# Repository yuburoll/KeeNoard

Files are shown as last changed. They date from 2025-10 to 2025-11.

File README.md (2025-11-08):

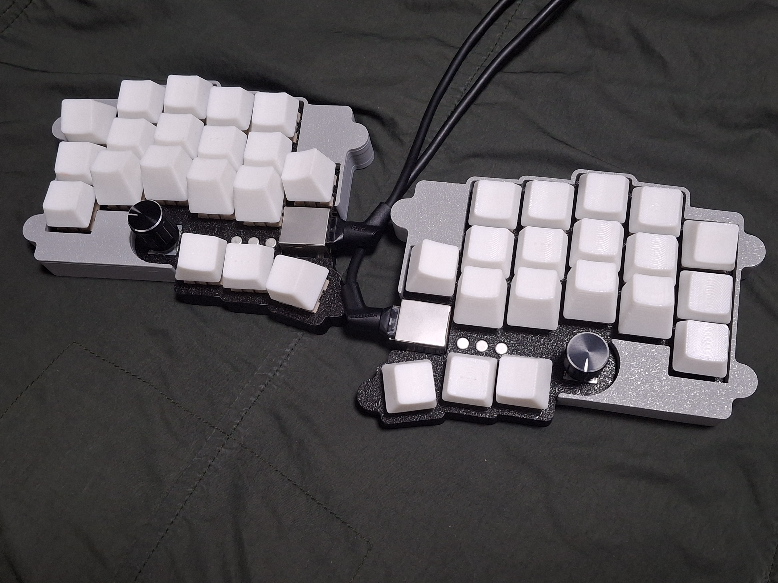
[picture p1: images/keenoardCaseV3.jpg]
keenoardCaseV3


# KeeNoard

**KeeNoard**(name intended typo between B and N) is 38-key split keyboard with rotary encoder and multiple center key, with only one rp2040 zero board.

Inspired and learned many thing from the former great [Cheapino](https://github.com/tompi/cheapino), KeeNoard uses only one board and [Japanese duplex matrix](https://kbd.news/The-Japanese-duplex-matrix-1391.html), and controlled ghosting with three PNP transistor and active-high matrix.

Default keymap uses customized [Miryoku](https://github.com/manna-harbour/miryoku) - with slight different mouse and navigator keys. Two center keys are mapped to left Y and right B, which are originally intended.

## Preparation

- 1x rp2040 zero (boards formly created by waveshare) (Approx. 2-4$)

- 2x KeeNoard PCB Boards (5 boards are 9$ on JLC w/o shipping cost)

- 1x printed case sets, which you want to make it (Approx. 8-12$ if you buy printed one)

- 6x TO-18 PNP transistors, or 6x SOT-23 PNP transistors. (Approx. 1-2$)

- 50x diodes (Approx. 1$)

- 2x EC11 encoders and cap (Approx. 2$)

- 14x M2x6 screws, flathead (Approx. 1$)

- 1x RJ45 cable (Approx. 3$)

- 2x RJ45 connector, in 18mm (Approx. 1$)

- 38x Keyswitches & Keycaps (Maybe this costs varies too much. 15$ on average)

Approx. 43$-50$(w/o shipping cost) needed to build one

## Build Guides

work in progress. sorry!

You can see the images in the folder, which uploaded for build guides. Especially you may see how to solder the controller board, because this uses surface mounting by castelated pins.

Images are captured with prototype version PCB, which is different from the current gerber. current gerber has SMD transistor soldering pads on the protype's label position, and is more easy to solder controller board with larger soldering pads.

This uses [qmk](https://qmk.fm/) to build the firmware. Copy "keenoard" folder which is in "firmware" directory to "qmk_firmware\keyboards" folder, and build it via qmk msys.

Or, simply flash uf2 in "uf2Examples" folder by changing rp2040 zero in dfu mode, which can be executed by holding boot button while plugging in usb c. Vial versions are also prepared - use proper vial firmware, depending on where you placed the controller board.

## Licenses

matrix.c and other qmk-related things follows GNU GPL license.

other codes follows MIT license.

all designs and the hardware board follows CC BY-SA 4.0 license.

If you want to make a commercial product, it would be appreciated [if you sponsor some bucks for me.](https://github.com/sponsors/yuburoll)

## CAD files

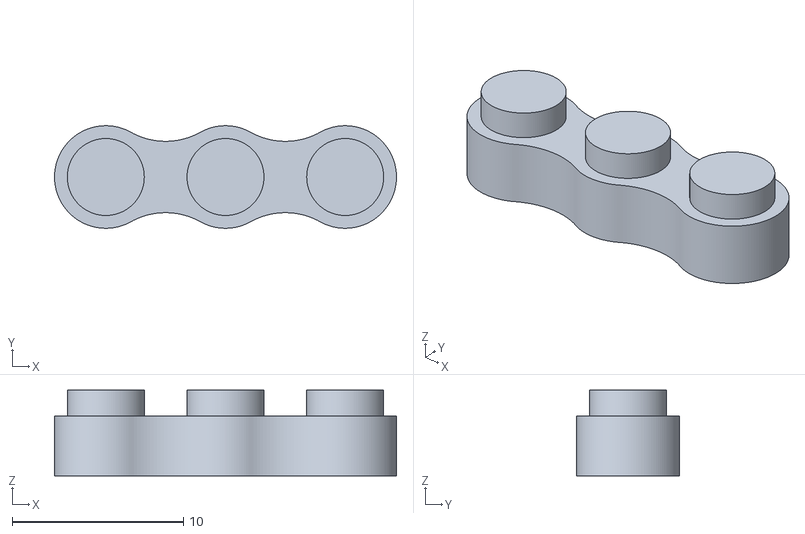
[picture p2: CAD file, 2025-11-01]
case/KeeNoardCase_TransistorCap.stl
20.0 x 6.00 x 5.00

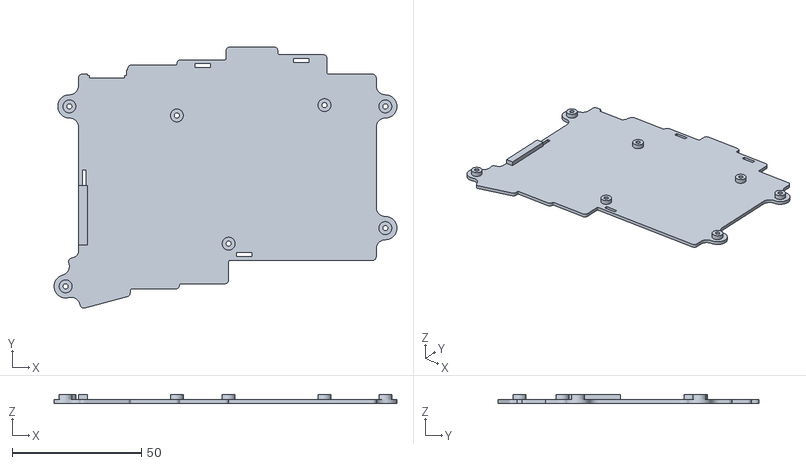
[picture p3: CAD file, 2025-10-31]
case/V3/leftboard/KeeNoardCaseV3_LBoard_RDown.stl
132.5 x 100.9 x 3.50

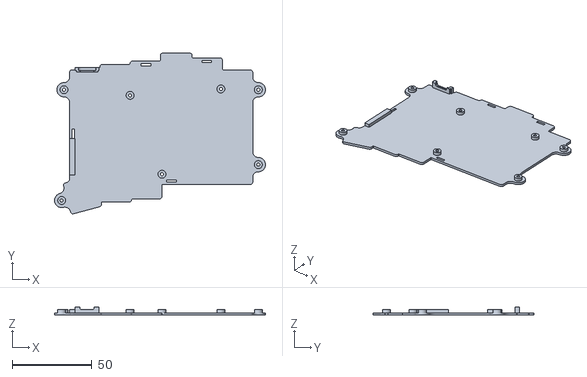
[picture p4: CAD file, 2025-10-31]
case/V3/rightboard/KeeNoardCaseV3_RBoard_RDown.stl
132.5 x 100.9 x 5.25

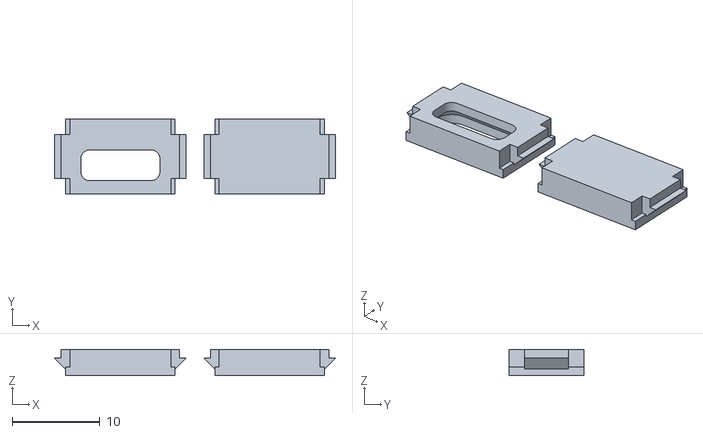
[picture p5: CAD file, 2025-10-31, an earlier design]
case/V2/KeeNoardCaseV2_Slit.stl
32.0 x 8.50 x 3.00

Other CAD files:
case/V1/leftboard/KeeNoardCaseV1_LBoard_RDown.stl
case/V1/rightboard/KeeNoardCaseV1_RBoard_LDown.stl
case/V1/leftboard/KeeNoardCaseV1_LBoard_LDown.stl
case/V1/rightboard/KeeNoardCaseV1_RBoard_RDown.stl

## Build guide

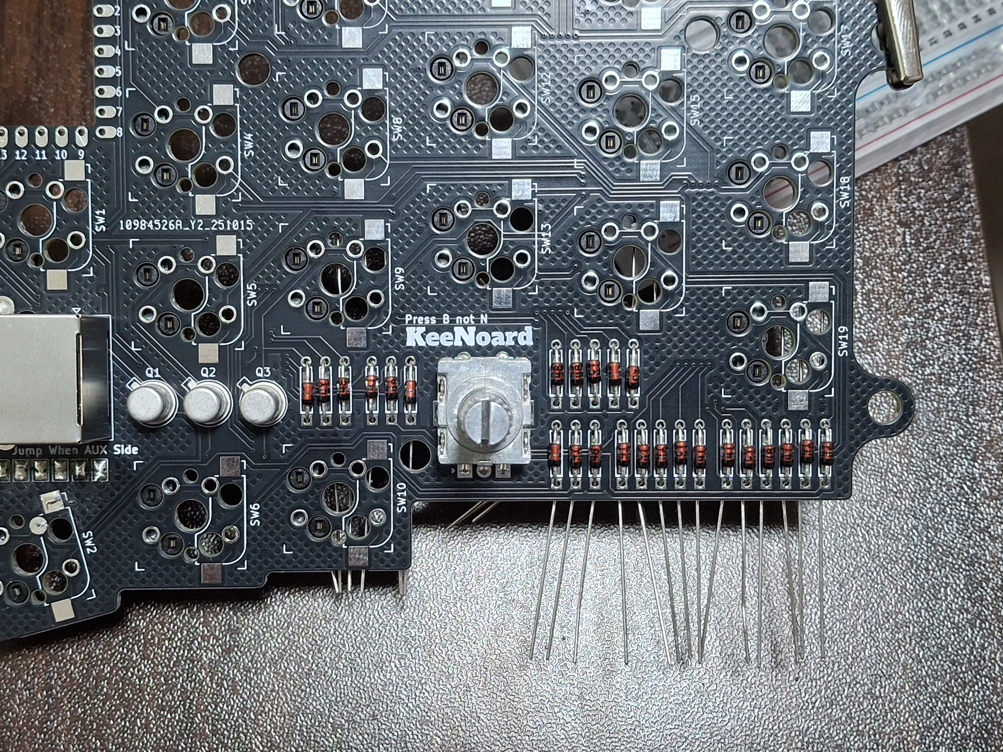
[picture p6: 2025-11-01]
images/diodesSolder1.jpg

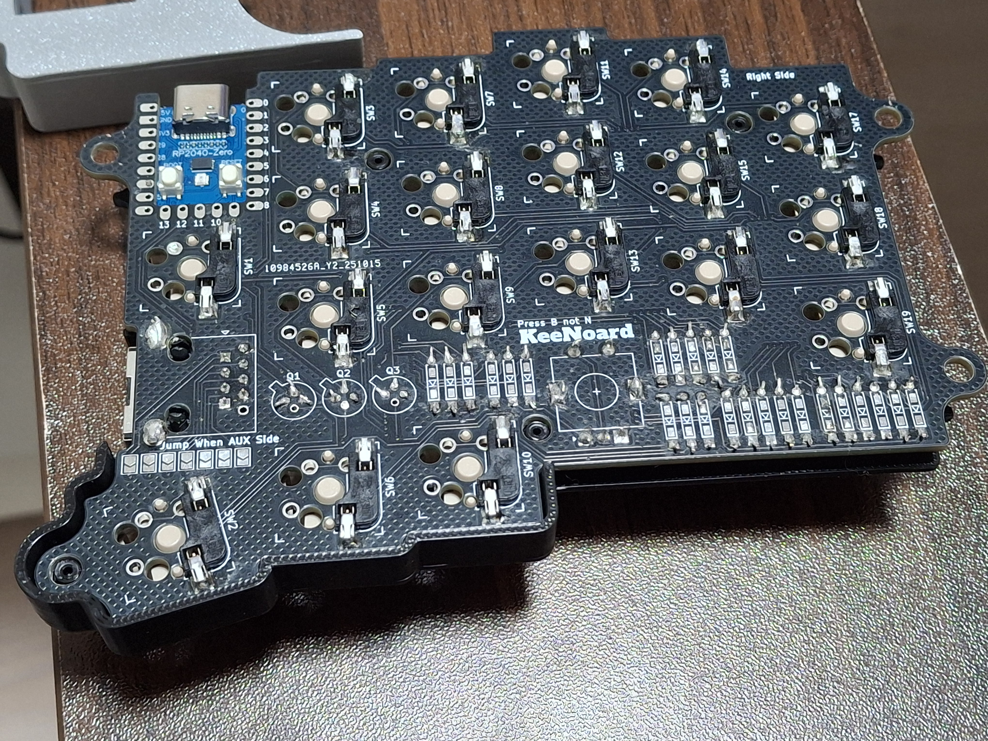
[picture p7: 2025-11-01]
images/caseV3Assembly3.jpg

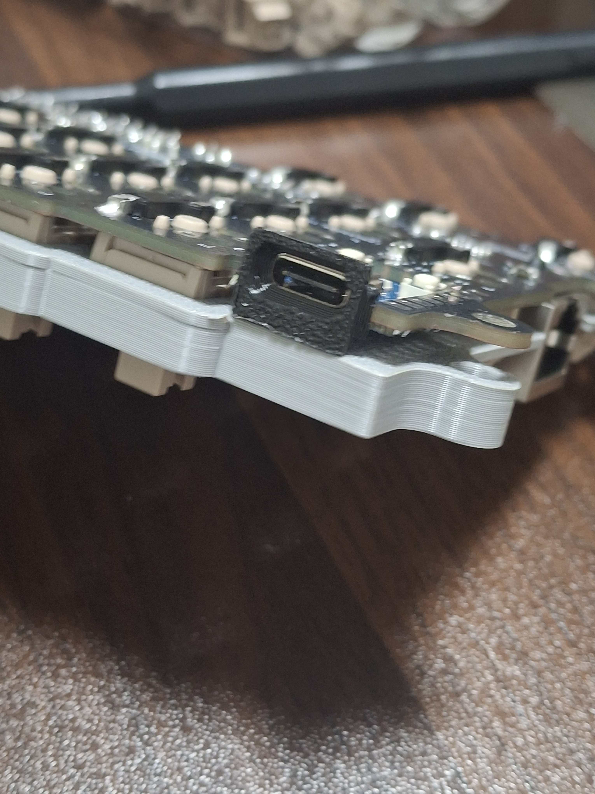
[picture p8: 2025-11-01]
images/caseV2Assembly5.jpg

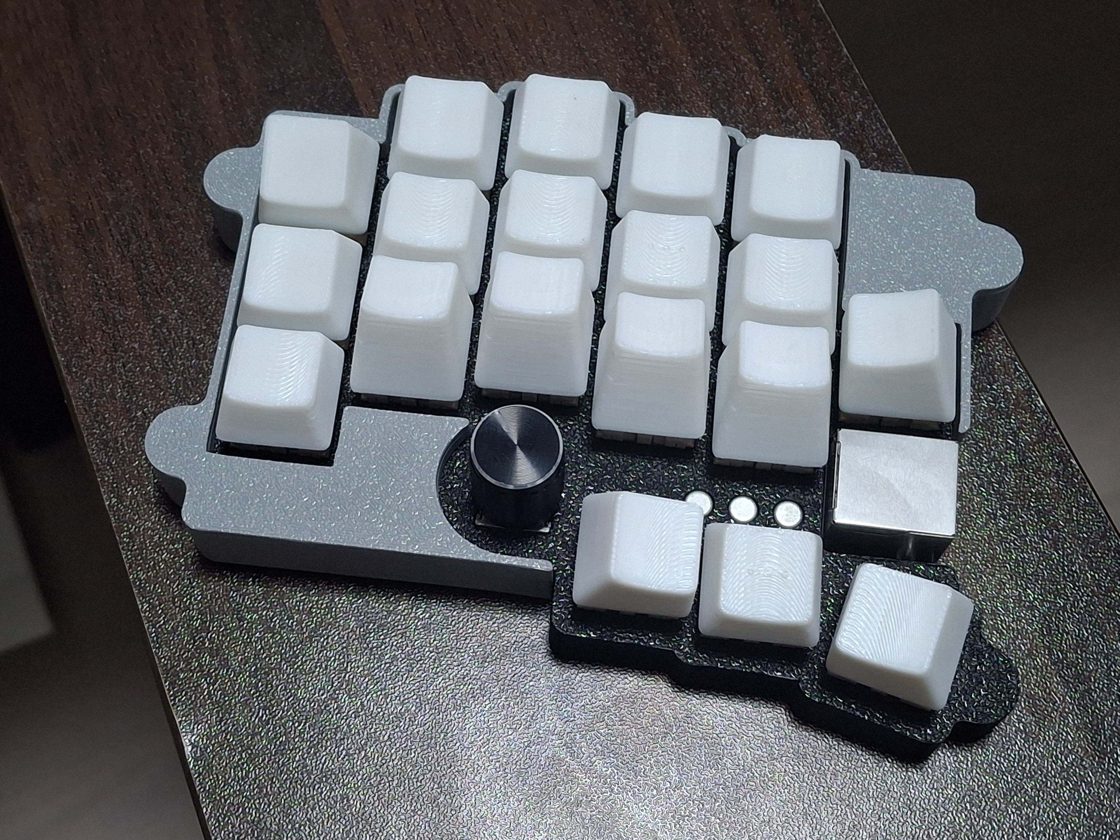
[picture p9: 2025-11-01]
images/caseV3Assembly7.jpg

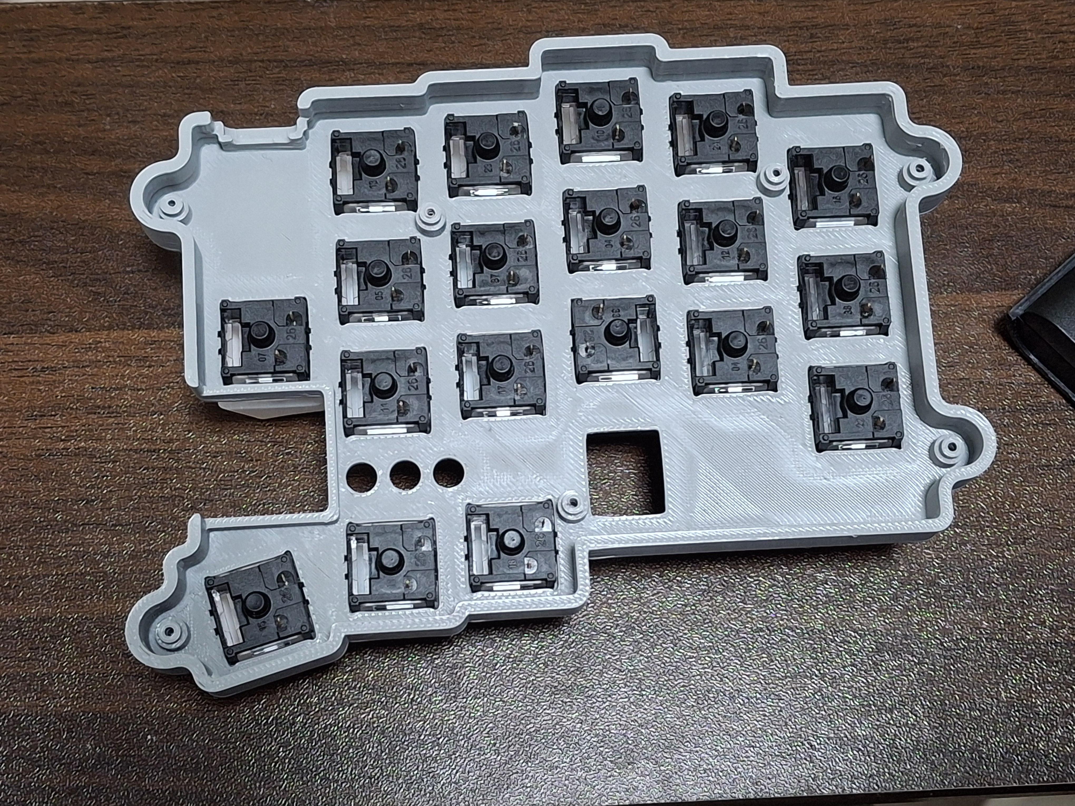
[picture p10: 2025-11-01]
images/caseV1Assembly2.jpg

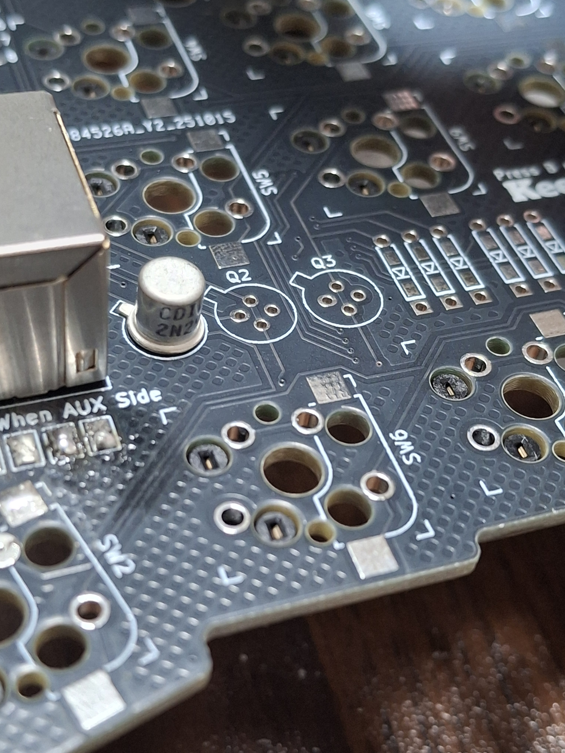
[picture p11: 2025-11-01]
images/transistorSolder0.jpg

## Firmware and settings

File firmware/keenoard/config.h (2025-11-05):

#pragma once

#define MATRIX_ROW_PULLS MATRIX_PULL_DOWN
#define MATRIX_COL_PULLS MATRIX_PULL_DOWN
#define NUM_ENCODERS 2

#undef TAPPING_TERM
#define TAPPING_TERM 200
#ifndef QUICK_TAP_TERM_PER_KEY
    #define QUICK_TAP_TERM_PER_KEY
#endif
#define QUICK_TAP_TERM 120
#ifndef PERMISSIVE_HOLD_PER_KEY
    #define PERMISSIVE_HOLD_PER_KEY
#endif
#ifndef HOLD_ON_OTHER_KEY_PRESS_PER_KEY
    #define HOLD_ON_OTHER_KEY_PRESS_PER_KEY
#endif
#define BOTH_SHIFTS_TURNS_ON_CAPS_WORD

#undef MOUSEKEY_DELAY
#define MOUSEKEY_DELAY          0
#undef MOUSEKEY_INTERVAL
#define MOUSEKEY_INTERVAL       16
#undef MOUSEKEY_WHEEL_DELAY
#define MOUSEKEY_WHEEL_DELAY    0
#undef MOUSEKEY_MAX_SPEED
#define MOUSEKEY_MAX_SPEED      6
#undef MOUSEKEY_TIME_TO_MAX
#define MOUSEKEY_TIME_TO_MAX    64

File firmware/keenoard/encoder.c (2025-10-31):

#include "encoder.h"
#include "action.h"
#include "quantum.h"
#include "timer.h"

#define COL_SHIFTER ((uint16_t)1)

#define ENCODER_0_ROW 3
#define ENCODER_0_COL_A 5
#define ENCODER_0_COL_B 3

#define ENCODER_1_ROW 7
#define ENCODER_1_COL_A 9
#define ENCODER_1_COL_B 11

__attribute__((weak)) void encoder_init(void) {}

__attribute__((weak)) bool encoder_queue_event(uint8_t index, bool clockwise) {
    return false;
}
__attribute__((weak)) bool encoder_dequeue_event(uint8_t *index, bool *clockwise) {
    return false;
}

static bool col0PressedAB = false;
static bool col1PressedAB = false;
static fast_timer_t last_encoding_time = 0;
static const fast_timer_t ENCODER_DEBOUNCE = 50;

void custom_encoder_update_kb(uint8_t index, bool clockwise) {

    switch (index) {
        case 0:
            if (clockwise) {
                #if defined(MOUSEKEY_ENABLE)
                    tap_code16(QK_MOUSE_WHEEL_UP);
                #elif defined(EXTRAKEY_ENABLE)
                    tap_code(KC_VOLU);
                #else
                    tap_code(KC_PGDN);
                #endif
            } else {
                #if defined(MOUSEKEY_ENABLE)
                    tap_code16(QK_MOUSE_WHEEL_DOWN);
                #elif defined(EXTRAKEY_ENABLE)
                    tap_code(KC_VOLD);
                #else
                    tap_code(KC_PGUP);
                #endif
            }
            break;
        case 1:
            if (clockwise) {
                #if defined(MOUSEKEY_ENABLE)
                    tap_code16(QK_MOUSE_WHEEL_LEFT);
                #elif defined(EXTRAKEY_ENABLE)
                    tap_code(KC_MNXT);
                #else
                    tap_code(KC_RIGHT);
                #endif
            } else {
                #if defined(MOUSEKEY_ENABLE)
                    tap_code16(QK_MOUSE_WHEEL_RIGHT);
                #elif defined(EXTRAKEY_ENABLE)
                    tap_code(KC_MPRV);
                #else
                    tap_code(KC_LEFT);
                #endif
            }
            break;
    }
}

// do action when turned
void turned(uint8_t index, bool clockwise) {
    if (TIMER_DIFF_FAST(timer_read_fast(), last_encoding_time) >= ENCODER_DEBOUNCE) {
        last_encoding_time = timer_read_fast();
    } else {
        return;
    }

    #ifdef ENCODER_MAP_ENABLE
        action_exec(clockwise ? MAKE_ENCODER_CW_EVENT(index, true) : MAKE_ENCODER_CCW_EVENT(index, true));
        action_exec(clockwise ? MAKE_ENCODER_CW_EVENT(index, false) : MAKE_ENCODER_CCW_EVENT(index, false));
    #else
        custom_encoder_update_kb(index, clockwise);
    #endif
}

void custom_encoder_action(matrix_row_t current_matrix[]) {
    matrix_row_t encoder_row;
    bool colCheckA;
    bool colCheckB;

    // ENCODER_0 check matrix
    encoder_row = current_matrix[ENCODER_0_ROW];
    colCheckA = encoder_row & (COL_SHIFTER << ENCODER_0_COL_A);
    colCheckB = encoder_row & (COL_SHIFTER << ENCODER_0_COL_B);

    if (colCheckA && colCheckB) {
        col0PressedAB = true;
    } else if (colCheckA) {
        if (col0PressedAB) {
            col0PressedAB = false;
            turned(0, true);
        }
    } else if (colCheckB) {
        if (col0PressedAB) {
            col0PressedAB = false;
            turned(0, false);
        }
    }

    // ENCODER_0 flush encoder point
    encoder_row &= ~(COL_SHIFTER << ENCODER_0_COL_A);
    encoder_row &= ~(COL_SHIFTER << ENCODER_0_COL_B);

    // ENCODER_1 check matrix
    encoder_row = current_matrix[ENCODER_1_ROW];
    colCheckA = encoder_row & (COL_SHIFTER << ENCODER_1_COL_A);
    colCheckB = encoder_row & (COL_SHIFTER << ENCODER_1_COL_B);

    if (colCheckA && colCheckB) {
        col1PressedAB = true;
    } else if (colCheckA) {
        if (col1PressedAB) {
            col1PressedAB = false;
            turned(1, true);
        }
    } else if (colCheckB) {
        if (col1PressedAB) {
            col1PressedAB = false;
            turned(1, false);
        }
    }

    // ENCODER_1 flush encoder point
    encoder_row &= ~(COL_SHIFTER << ENCODER_1_COL_A);
    encoder_row &= ~(COL_SHIFTER << ENCODER_1_COL_B);
}

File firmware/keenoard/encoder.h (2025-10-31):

/*
keymappable encoder
referenced by Thomas Hakuland's code https://github.com/tompi/qmk_firmware/blob/cheapinov2/keyboards/cheapino/encoder.c

*/

#pragma once

#include <stdint.h>
#include <stdbool.h>
#include "gpio.h"
#include "util.h"
#include "matrix.h"

#ifdef ENCODER_ENABLE

    #ifndef NUM_ENCODERS
        #define NUM_ENCODERS 2
    #endif
    #define ENCODER_RESOLUTION 4
    #define NUM_ENCODERS_LEFT NUM_ENCODERS
    #define NUM_ENCODERS_RIGHT 0
    #define NUM_ENCODERS_MAX_PER_SIDE MAX(NUM_ENCODERS_LEFT, NUM_ENCODERS_RIGHT)
    
    #ifdef ENCODER_MAP_ENABLE
        #define MAKE_ENCODER_CW_EVENT(enc_id, press) MAKE_EVENT(KEYLOC_ENCODER_CW, (enc_id), (press), ENCODER_CW_EVENT)
        #define MAKE_ENCODER_CCW_EVENT(enc_id, press) MAKE_EVENT(KEYLOC_ENCODER_CCW, (enc_id), (press), ENCODER_CCW_EVENT)
        #define NUM_DIRECTIONS 2
        extern const uint16_t encoder_map[][NUM_ENCODERS][NUM_DIRECTIONS];
    #endif
    
    __attribute__((weak)) void encoder_init(void);
    __attribute__((weak)) bool encoder_queue_event(uint8_t index, bool clockwise);
    __attribute__((weak)) bool encoder_dequeue_event(uint8_t *index, bool *clockwise);

    void custom_encoder_action(matrix_row_t current_matrix[]);

#endif

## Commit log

2025-10-31 first update
    [KeeNoard-SMD-B_Cu.gbr, KeeNoard-SMD-B_Mask.gbr, KeeNoard-SMD-B_Paste.gbr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]
2025-11-01 Create KeeNoardCase_TransistorCap.stl
    this is cap for transistor, for which does not use to18 transistors.
    [KeeNoardCase_TransistorCap.stl]
